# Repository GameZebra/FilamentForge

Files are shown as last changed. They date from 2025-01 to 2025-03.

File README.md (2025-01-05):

# FilamentForge
A machine that recycles PET bottles into filament for 3d printing.
Everything you'll need.

# FIle organization:
* Hardware:
    * Parts:
        * includes a list of all electrical components used
    * 3D models:
        * Containing all the 3d printed parts, model of the complete assembly and building instructions
* system_control:
    * system_identification
        * instructions how to make matematical models of your particular parts
        * MatLab example codes for my version
    * regulators:
        * using the models form the identification step to tune well the regulators
        * again with MatLab example codes
* stm32_code:
    * test_regulator_
        * containing the software implementation for the proposed regulators (used like Unit testing)
    * FilamentForge_complete
        * where all the components are combined

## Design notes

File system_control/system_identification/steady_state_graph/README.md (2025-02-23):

the controll is achieved with one powerfull MOSFET that controls the voltage trough the heater

the reading of the temperature is achieved by reading the voltage drop over a termistor connected in a voltage delitel 
the known resistances are discretisized in 3 sectors:
32.5 kOhm
2.5 kOhm
150 Ohm

(they were calculated using the matlab files in the upper folder)
the swap between the reading ranges is done by using MOSFETS to control if a specific resistor is connecred or not

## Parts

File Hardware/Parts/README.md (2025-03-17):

the current state of the heating element is using 3 MOSFETS to swap between the different ranges for more precise measurment of the temperature.

__It is good to know that the MOSFETS althou don't have currnet use, they work like Capacitors and as such you should be warned that they may discharge trough your MCU board and frie something.

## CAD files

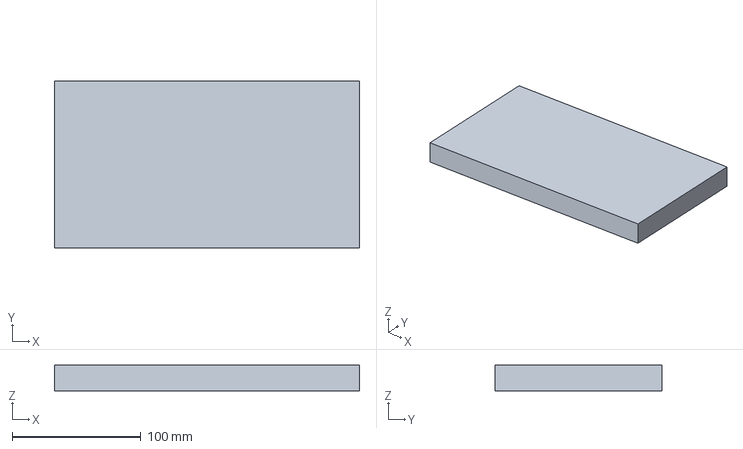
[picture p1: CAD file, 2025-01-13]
Hardware/3D models/FreeCad/base.FCStd
237.0 x 130.0 x 20.0 mm

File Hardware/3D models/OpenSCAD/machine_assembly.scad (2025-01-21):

// BASE

base_hight = 20;

// positionnig
translate([0,0,base_hight/2]){

    color("yellow", 1.0){
        cube([237, 130, base_hight], center = true);
    }   
}

// EXTRUDER HOLDER

    square_size = 40;
    hole_offset = 0;
    circle_size = 4.55;


// positionning
translate([0,0,base_hight]){

    difference(){
    color("blue", 1.0){
        //base 
        square(square_size, center = true);


        

        //side
        translate([(square_size/2)-0.5,0,(square_size/2)-0.5]){
            rotate([0, 90, 0]){
                square(square_size, center = true);
            }
        }
        
    }
        // holes base
        color("yellow", 1.0){
            for(i = [0:2]){
                rotate([0,0,120*i])
                translate([11.5,0,0])
                circle(circle_size, $fn = 100);       
            }
         // holes side
            translate([(square_size/2)-0.5,0,(square_size/2)-0.5])
            rotate([0,90,0])
            
            
            for(i = [0:2]){
                rotate([0,0,120*i+30])
                translate([0,11.5,0])
                circle(circle_size, $fn = 100);       
            }
              
        }
    }
}

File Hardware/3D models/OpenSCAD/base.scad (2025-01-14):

cube([237, 130, 20], center = true);

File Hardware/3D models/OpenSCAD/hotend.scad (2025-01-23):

cube([20,20,10], center = true);

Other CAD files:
Hardware/3D models/OpenSCAD/extruder_holder.scad
Hardware/3D models/OpenSCAD/nozzle.scad

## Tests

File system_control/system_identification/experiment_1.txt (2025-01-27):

Voltage, Current, Resistance, Temperature
0, 0.000, 96970, 24.5,
1, 0.125, 93100, 24.5,
2, 0.257, 88240, 25.5,
2, 0.257, 83660, 26.5,
2, 0.257, 80820, 27.0,
2, 0.257, 79580, 27.5,
3, 0.387, 68710, 29.8,
3, 0.387, 65980, 30.5,
3, 0.386, 63240, 31.5,
3, 0.386, 58850, 32.4,
4, 0.517, 52190, 34.5,
4, 0.517, 49380, 35.5,
4, 0.517, 44690, 38.0,
4, 0.517, 41740, 39.5,
5, 0.644, 34740, 42.5,
5, 0.644, 31140, 44.5,
5, 0.644, 28430, 46.0,
5, 0.644, 23450, 48.5,
5, 0.644, 19930, 51.5,
5, 0.644, 19780, 52.5,
6, 0.769, 19620, 57.0,
6, 0.769, 16630, 58.6,
6, 0.769, 14840, 62.0,
7, 0.896, 13210, 63.5,
7, 0.896, 13210, 69.0,
7, 0.896, 9006, 71.5,
7, 0.896, 7721, 76.5,
7, 0.896, 6691, 84.5,
8, 1.022, 6129, 86.6,
8, 1.022, 5159, 90.5,
8, 1.020, 4898, 93.0,
8, 1.020, 4069, 101.0,
8, 1.019, 3827, 103.5,
9, 1.146, 3132, 104.5, 
9, 1.144, 2014, 122.5,
10, 1.269, 1747, 126.5,
10, 1.269, 1381, 132.5,
10, 1.268, 1252, 136.5,
10, 1.268, 1161, 141.5,
10, 1.267, 1067, 144.5,
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

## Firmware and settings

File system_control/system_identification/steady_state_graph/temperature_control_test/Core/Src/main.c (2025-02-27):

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
/* Includes ------------------------------------------------------------------*/
#include "main.h"
#include "math.h"

/* USER CODE BEGIN PD */
#define logicVoltage 4.59
/* USER CODE END PD */

ADC_HandleTypeDef hadc1;

TIM_HandleTypeDef htim4;

/* USER CODE BEGIN PV */
uint16_t const rangeLow = 4095*0.25;
uint16_t const rangeHigh = 4095*0.8;
uint16_t adcValue = 0;

// reading constants
uint16_t const resistance[3] = {34350, 2220, 149}; //34350
double const paramA[3] = {5487.3, 84.1512, 4.2549};
double const paramB[3] = {72.6241, 371.3556, 827.1895};

uint32_t range[3] = {0x0, 0x1, 0x3};
uint8_t state = 0;
float termistorVoltage = 0;
float currentResistor = 0;
float termistorResistance = 0;
double calculatedTemperature = 0;
// Rt3 = A3.*exp(B3./Temperature(45:60));
// formula to digitalize



/* USER CODE END PV */

void SystemClock_Config(void);
static void MX_GPIO_Init(void);
static void MX_ADC1_Init(void);
static void MX_TIM4_Init(void);
/**
  * @brief  The application entry point.
  * @retval int
  */
int main(void)
{

  /* MCU Configuration--------------------------------------------------------*/

  /* Reset of all peripherals, Initializes the Flash interface and the Systick. */
  HAL_Init();

  /* Configure the system clock */
  SystemClock_Config();

  /* Initialize all configured peripherals */
  MX_GPIO_Init();
  MX_ADC1_Init();
  MX_TIM4_Init();
  /* USER CODE BEGIN 2 */

  // TODO new MOSFETS
  // Trying BS170p
  HAL_GPIO_WritePin(range1_GPIO_Port, range1_Pin, 0);
  HAL_GPIO_WritePin(range2_GPIO_Port, range2_Pin, 0);

  __HAL_TIM_SET_COMPARE(&htim4, TIM_CHANNEL_1, 0);
  HAL_TIM_PWM_Start(&htim4, TIM_CHANNEL_1);
  /* USER CODE END 2 */

  /* Infinite loop */
  /* USER CODE BEGIN WHILE */
  while (1)
  {
	  HAL_ADC_Start(&hadc1);
	  HAL_ADC_PollForConversion(&hadc1, 100);
	  adcValue = HAL_ADC_GetValue(&hadc1);
	  HAL_ADC_Stop(&hadc1);

	 /* if ((adcValue > rangeHigh) && state != 0){
		  state--;
		  GPIOB->ODR = range[state];
		  HAL_Delay(300);
		  continue;
	  }
	  else if ((adcValue < rangeLow) && state != 2){
		  state++;
		  GPIOB->ODR = range[state];
		  HAL_Delay(300);
		  continue;
	  }*/

	  // calculate termistor voltage drop
	  termistorVoltage = (adcValue/4095.0) * (logicVoltage - 1.61);
	  currentResistor = resistance[state];
	  termistorResistance = currentResistor * (termistorVoltage / ((logicVoltage - 1.61) - termistorVoltage));
	  calculatedTemperature = paramB[state] / (log(termistorResistance)-log(paramA[state]));
	  HAL_Delay(10);


    /* USER CODE END WHILE */

    /* USER CODE BEGIN 3 */
  }
  /* USER CODE END 3 */
}

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


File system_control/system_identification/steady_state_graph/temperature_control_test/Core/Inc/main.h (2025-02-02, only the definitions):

#define range1_Pin GPIO_PIN_0
#define range1_GPIO_Port GPIOB
#define range2_Pin GPIO_PIN_1
#define range2_GPIO_Port GPIOB

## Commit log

2025-01-05 gitignore for stm32 Cube and Matlab files
2025-01-12 base 3d model cad
    [base.FCStd]
2025-01-13 base finished
    [base.FCStd]
2025-01-14 files reordered
    [base.FCStd]
2025-01-14 base done with openSCAD
    [base.scad]
2025-01-17 base for extruder holder
    [extruder_holder.scad]
2025-01-17 base parametric fix
    [extruder_holder.scad]
2025-01-17 hola init
    [extruder_holder.scad]
2025-01-19 holes at place
    [extruder_holder.scad]
2025-01-19 holes driled
    [extruder_holder.scad]
2025-01-21 assembly of the full machine
    [machine_assembly.scad]
2025-01-22 nozzle model
    [nozzle.scad]
2025-01-23 model for hotend
    [hotend.scad]
2025-01-27 temperature mesurment init
2025-01-28 resistors chosen
2025-02-01 matched the reanges of the resistors and the approximation formula
2025-02-02 adc added + clocks fixed
    [main.c, main.h, temperature_control_test.ioc]
2025-02-19 check the range mosfets
2025-02-19 TODO swap the MOSFETS with NO
    [main.c]
2025-02-23 trying new MOSFETS
2025-02-25 turning on and off the controll MOSFETS
2025-02-25 calculates the temperature
2025-02-25 measures with error with resistances and distance between them
    [main.c]
2025-02-27 the schematic needs a diode to block the reverse current
    [main.c]

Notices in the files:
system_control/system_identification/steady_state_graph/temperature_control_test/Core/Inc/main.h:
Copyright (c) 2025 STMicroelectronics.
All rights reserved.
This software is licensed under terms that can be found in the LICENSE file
